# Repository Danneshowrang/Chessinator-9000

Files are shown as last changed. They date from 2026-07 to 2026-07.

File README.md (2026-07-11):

# Chessinator-9000
A smart open source folding chessboard. Future expansions planned with electromagnetic gantry.


# About
This board utilizes a network of hall sensors to track and log moves. Made up of 2 adjacent PCBs and designed to be foldable for improved portability. Future plans include a supplementary electromagnetic gantry and API connection to Lichess and Chess.com. Currently configured to project move and take a crowdvote for Open Sauce.

# Pictures
Screenshot 2026-07-11 at 2 22 00 AM
Chessinator_9000_Assembly_2_v1_2026-Jul-11_06-53-40AM-000_CustomizedView4809420216_jpg




# CAD
Link to Onshape: https://cad.onshape.com/documents/2e4e2dec579cd54b02eea52a/w/9b3b1f51bd0c7211bdccebd8/e/a09db839a12e81c960572c26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

# Bill Of Materials
Screenshot 2026-07-11 at 6 36 42 AM

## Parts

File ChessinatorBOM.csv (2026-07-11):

Name | Price | Link | Quantity
XT30 Plug* | $0.38 | https://jlcpcb.com/partdetail/Changzhou_AmassElec-XT30PW_M30_GY/C431092 | 1
Hall Sensor* | $0.11 | https://jlcpcb.com/partdetail/GoChip_Elec_Tech_Shanghai-GH49FEUAC/C92332 | 64
3.4A Inductor* | $0.06 | https://jlcpcb.com/partdetail/146573-SMNR4020_22UH/C135262 | 3
10A Fuse* | $0.21 | https://jlcpcb.com/partdetail/BHFUSE-BSMD1206L500/C914097 | 2
23V Diode* | $4.75 | https://jlcpcb.com/partdetail/10752-SMBJ18A/C10212 | 2
Polarized Caps* | $0.04 | https://jlcpcb.com/partdetail/DMBJ-RVT1E470M0605_47UF25V/C970677 | 2
AO3401A MOSFET | $0.10 | https://jlcpcb.com/partdetail/Alpha_OmegaSemicon-AO3401A/C15127 | 2
12-pin FFC* | $0.10 | https://jlcpcb.com/partdetail/JUSHUO-AFC07_S12FCA00/C262559 | 2
Ceramic Caps | $0.03 | https://jlcpcb.com/partdetail/YAGEO-CC0603KRX7R9BB104/C14663 | 4
ESP-32-S3-N16* | $5.42 | https://jlcpcb.com/partdetail/3198297-ESP32_S3_WROOM_1N16/C2913199 | 1
SOIC-24 MUX* | $0.67 | https://jlcpcb.com/partdetail/TexasInstruments-CD74HC4067M96/C496123 | 4
3.3V Buck* | $0.61 | https://jlcpcb.com/partdetail/DiodesIncorporated-AP63203WU7/C780769 | 1
5V Buck* | $0.56 | https://jlcpcb.com/partdetail/DiodesIncorporated-AP63201WU7/C2071044 | 1
USB-C* | $0.10 | https://jlcpcb.com/partdetail/HCTL-HC_TYPE_C_16P01A/C2894897 | 1
Gross: | $27.49 | "+ shipping"
Pick & Place: | 36 | * - +$3 one-time extended fee for pick and place machine
Total: | $63.49

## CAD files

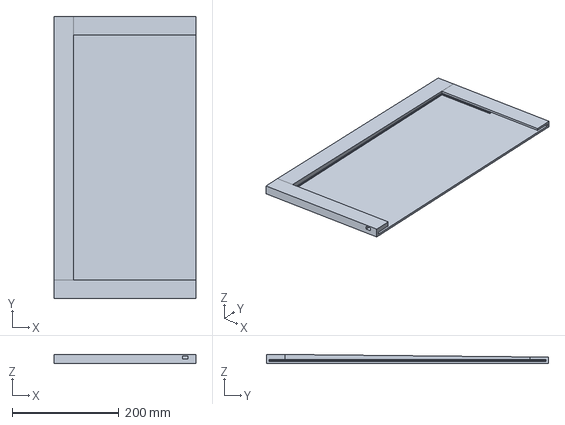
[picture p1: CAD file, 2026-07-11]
Chessinator CAD Files/Chessinator 9000 Left Case Piece.step
264.9 x 527.3 x 17.0 mm

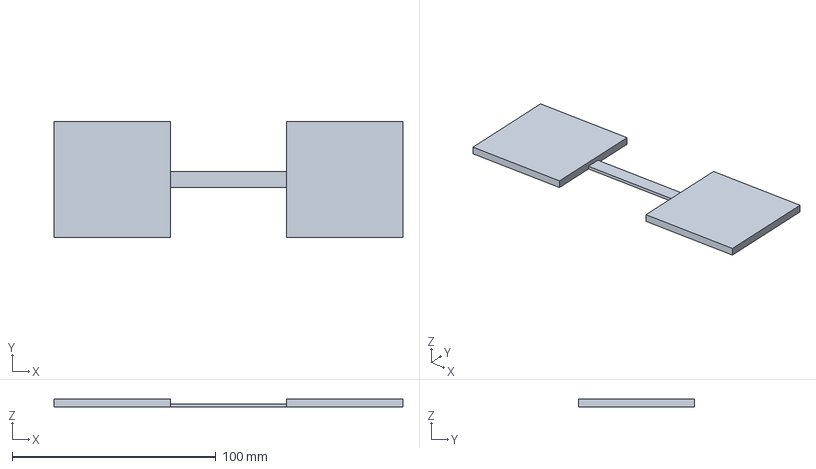
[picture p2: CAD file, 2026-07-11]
Chessinator CAD Files/Chessinator 9000 Dark Square Piece.step
171.4 x 57.1 x 4.00 mm

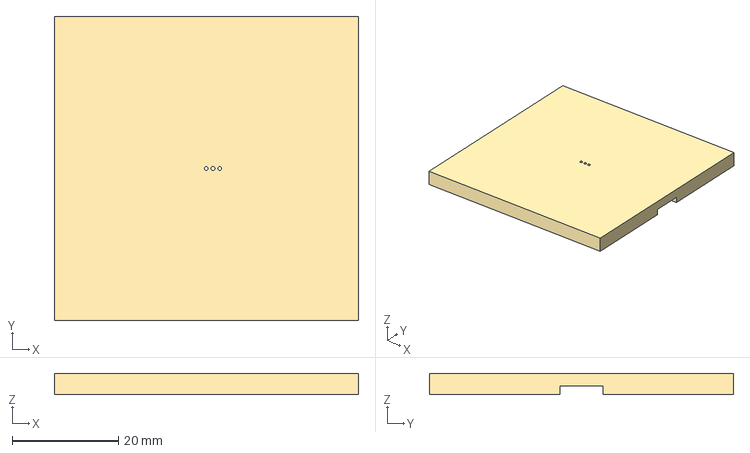
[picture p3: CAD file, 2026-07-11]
Chessinator CAD Files/Chessinator 9000 Light Square Piece.step
57.1 x 57.1 x 4.00 mm

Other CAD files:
Chessinator CAD Files/Chessinator 9000 Right Case Piece.step

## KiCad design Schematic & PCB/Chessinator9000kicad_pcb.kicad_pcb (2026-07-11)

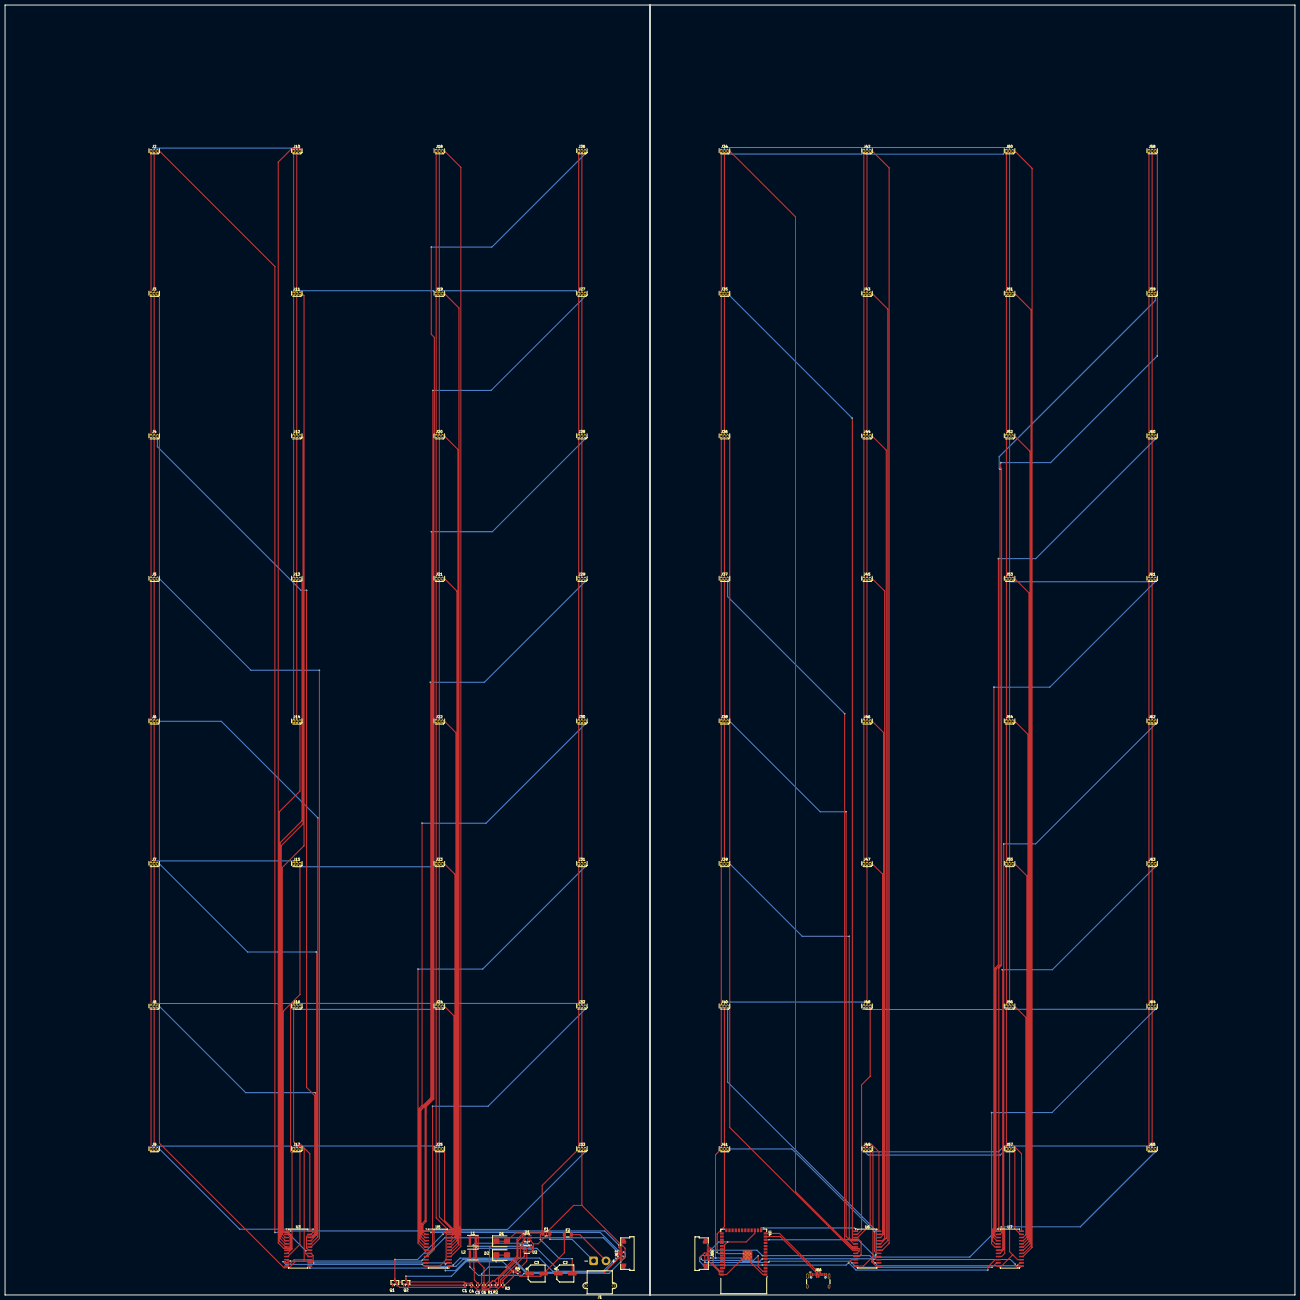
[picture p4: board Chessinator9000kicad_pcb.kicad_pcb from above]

Board: 2 copper layers, 517.1 x 517.1 mm, 93 parts (0 on the bottom side), 91 nets.

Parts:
C1, C4, C5, C6: C; C_0603_1608Metric
C2, C3: C_Polarized; CP_Elec_6.3x5.4
D1, D2: D_TVS; D_SMB
F1, F2: Fuse; Fuse_1206_3216Metric
J1: Conn_01x02; AMASS_XT30PW-M_1x02_P2.50mm_Horizontal
J2, J3, J4, J5, J6, J7, J8, J9, J10, J11, J12, J13, J14, J15, J16, J17, J18, J19, J20, J21, J22, J23, J24, J25, J26, J27, J28, J29, J30, J31, J32, J33, J34, J35, J36, J37, J38, J39, J40, J41, J42, J43, J44, J45, J46, J47, J48, J49, J50, J51, J52, J53, J54, J55, J56, J57, J58, J59, J60, J61, J62, J63, J64, J65: Conn_01x03; TO-92S
J66: USB_C_Receptacle_USB2.0_16P; USB_C_Receptacle_HCTL_HC-TYPE-C-16P-01A
J67, J68: Conn_02x06_Odd_Even; Amphenol_F32Q-1A7x1-11012_1x12-1MP_P0.5mm_Horizontal
L1, L2: L; L_Coilcraft_XxL4020
Q1, Q2: PMOS; SOT-23
R1, R2, R3, R4: R; R_0603_1608Metric
U1: AP63203WU; TSOT-23-6
U2: AP63201WU; TSOT-23-6
U3, U5, U6, U7: CD74HC4067M; SOIC-24W_7.5x15.4mm_P1.27mm
U4: ESP32-S3-WROOM-1

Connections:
+3V3: C2.2, D1.1 (A1), D1.2 (A2), F1.1, J2.1 (VCC), J3.1 (VCC), J4.1 (VCC), J5.1 (VCC), J6.1 (VCC), J7.1 (VCC), J8.1 (VCC), J9.1 (VCC), J10.1 (VCC), J11.1 (VCC), J12.1 (VCC), J13.1 (VCC), J14.1 (VCC), J15.1 (VCC), J16.1 (VCC), J17.1 (VCC), J18.1 (VCC), J19.1 (VCC), J20.1 (VCC), J21.1 (VCC), J22.1 (VCC), J23.1 (VCC), J24.1 (VCC), J25.1 (VCC), J26.1 (VCC), J27.1 (VCC), J28.1 (VCC), J29.1 (VCC), J30.1 (VCC), J31.1 (VCC), J32.1 (VCC), J33.1 (VCC), J34.1 (VCC), J35.1 (VCC), J36.1 (VCC), J37.1 (VCC), J38.1 (VCC), J39.1 (VCC), J40.1 (VCC), J41.1 (VCC), J42.1 (VCC), J43.1 (VCC), J44.1 (VCC), J45.1 (VCC), J46.1 (VCC), J47.1 (VCC), J48.1 (VCC), J49.1 (VCC), J50.1 (VCC), J51.1 (VCC), J52.1 (VCC), J53.1 (VCC), J54.1 (VCC), J55.1 (VCC), J56.1 (VCC), J57.1 (VCC), J58.1 (VCC), J59.1 (VCC), J60.1 (VCC), J61.1 (VCC), J62.1 (VCC), J63.1 (VCC), J64.1 (VCC), J65.1 (VCC), J67.3, J67.4, J68.9, J68.10, Q1.3 (S), R1.1, R2.1, U3.24 (VCC), U4.2 (3V3), U5.24 (VCC), U6.24 (VCC), U7.24 (VCC)
+5V: C3.2, D2.1 (A1), D2.2 (A2), F2.1, Q2.3 (S), R3.1, R4.1
/Untitled Sheet/MUX3_COM: J67.9, J68.4, U4.17 (IO9), U4.38 (IO2), U5.1 (COM)
/Untitled Sheet/MUX4_COM: J67.10, J68.3
/Untitled Sheet/MUX_COM_EXTRA: J67.11, J68.2, U3.1 (COM), U4.39 (IO1)
/Untitled Sheet/MUX_S0: J67.5, J68.8, U3.10 (S0), U4.4 (IO4), U5.10 (S0), U6.10 (S0), U7.10 (S0)
/Untitled Sheet/MUX_S1: J67.6, J68.7, U3.11 (S1), U4.5 (IO5), U5.11 (S1), U6.11 (S1), U7.11 (S1)
/Untitled Sheet/MUX_S2: J67.7, J68.6, U3.14 (S2), U4.6 (IO6), U5.14 (S2), U6.14 (S2), U7.14 (S2)
/Untitled Sheet/MUX_S3: J67.8, J68.5, U3.13 (S3), U4.7 (IO7), U5.13 (S3), U6.13 (S3), U7.13 (S3)
GND: J2.2 (GND), J3.2 (GND), J4.2 (GND), J5.2 (GND), J6.2 (GND), J7.2 (GND), J8.2 (GND), J9.2 (GND), J10.2 (GND), J11.2 (GND), J12.2 (GND), J13.2 (GND), J14.2 (GND), J15.2 (GND), J16.2 (GND), J17.2 (GND), J18.2 (GND), J19.2 (GND), J20.2 (GND), J21.2 (GND), J22.2 (GND), J23.2 (GND), J24.2 (GND), J25.2 (GND), J26.2 (GND), J27.2 (GND), J28.2 (GND), J29.2 (GND), J30.2 (GND), J31.2 (GND), J32.2 (GND), J33.2 (GND), J34.2 (GND), J35.2 (GND), J36.2 (GND), J37.2 (GND), J38.2 (GND), J39.2 (GND), J40.2 (GND), J41.2 (GND), J42.2 (GND), J43.2 (GND), J44.2 (GND), J45.2 (GND), J46.2 (GND), J47.2 (GND), J48.2 (GND), J49.2 (GND), J50.2 (GND), J51.2 (GND), J52.2 (GND), J53.2 (GND), J54.2 (GND), J55.2 (GND), J56.2 (GND), J57.2 (GND), J58.2 (GND), J59.2 (GND), J60.2 (GND), J61.2 (GND), J62.2 (GND), J63.2 (GND), J64.2 (GND), J65.2 (GND), J67.1, J67.2, J68.11, J68.12, U1.4 (GND), U2.4 (GND), U3.12 (GND), U3.15 (~E), U4.1 (GND), U4.40 (GND), U4.41 (GND), U5.12 (GND), U5.15 (~E), U6.12 (GND), U6.15 (~E), U7.12 (GND), U7.15 (~E)
unnamed: C2.1, L1.1
unnamed: C3.1, L2.1
unnamed: F1.2, J1.1
unnamed: F2.2, J1.2
unnamed: J2.3 (PIT), U3.16 (I15)
unnamed: J3.3 (PIT), U3.17 (I14)
unnamed: J4.3 (PIT), U3.18 (I13)
unnamed: J5.3 (PIT), U3.19 (I12)
unnamed: J6.3 (PIT), U3.20 (I11)
unnamed: J7.3 (PIT), U3.21 (I10)
unnamed: J8.3 (PIT), U3.22 (I9)
unnamed: J9.3 (PIT), U3.23 (I8)
unnamed: J10.3 (PIT), U3.2 (I7)
unnamed: J11.3 (PIT), U3.3 (I6)
unnamed: J12.3 (PIT), U3.4 (I5)
unnamed: J13.3 (PIT), U3.5 (I4)
unnamed: J14.3 (PIT), U3.6 (I3)
unnamed: J15.3 (PIT), U3.7 (I2)
unnamed: J16.3 (PIT), U3.8 (I1)
unnamed: J17.3 (PIT), U3.9 (I0)
unnamed: J18.3 (PIT), U5.16 (I15)
unnamed: J19.3 (PIT), U5.17 (I14)
unnamed: J20.3 (PIT), U5.18 (I13)
unnamed: J21.3 (PIT), U5.19 (I12)
unnamed: J22.3 (PIT), U5.20 (I11)
unnamed: J23.3 (PIT), U5.21 (I10)
unnamed: J24.3 (PIT), U5.22 (I9)
unnamed: J25.3 (PIT), U5.23 (I8)
unnamed: J26.3 (PIT), U5.2 (I7)
unnamed: J27.3 (PIT), U5.3 (I6)
unnamed: J28.3 (PIT), U5.4 (I5)
unnamed: J29.3 (PIT), U5.5 (I4)
unnamed: J30.3 (PIT), U5.6 (I3)
unnamed: J31.3 (PIT), U5.7 (I2)
unnamed: J32.3 (PIT), U5.8 (I1)
unnamed: J33.3 (PIT), U5.9 (I0)
unnamed: J34.3 (PIT), U6.8 (I1)
unnamed: J35.3 (PIT), U6.9 (I0)
unnamed: J36.3 (PIT), U6.7 (I2)
unnamed: J37.3 (PIT), U6.6 (I3)
unnamed: J38.3 (PIT), U6.5 (I4)
unnamed: J39.3 (PIT), U6.4 (I5)
unnamed: J40.3 (PIT), U6.16 (I15)
unnamed: J41.3 (PIT), U6.17 (I14)
unnamed: J42.3 (PIT), U6.18 (I13)
unnamed: J43.3 (PIT), U6.19 (I12)
unnamed: J44.3 (PIT), U6.20 (I11)
unnamed: J45.3 (PIT), U6.21 (I10)
unnamed: J46.3 (PIT), U6.22 (I9)
unnamed: J47.3 (PIT), U6.23 (I8)
unnamed: J48.3 (PIT), U6.2 (I7)
unnamed: J49.3 (PIT), U6.3 (I6)
unnamed: J50.3 (PIT), U7.16 (I15)
unnamed: J51.3 (PIT), U7.17 (I14)
unnamed: J52.3 (PIT), U7.18 (I13)
unnamed: J53.3 (PIT), U7.19 (I12)
unnamed: J54.3 (PIT), U7.20 (I11)
unnamed: J55.3 (PIT), U7.21 (I10)
unnamed: J56.3 (PIT), U7.22 (I9)
unnamed: J57.3 (PIT), U7.23 (I8)
unnamed: J58.3 (PIT), U7.2 (I7)
unnamed: J59.3 (PIT), U7.3 (I6)
unnamed: J60.3 (PIT), U7.4 (I5)
unnamed: J61.3 (PIT), U7.5 (I4)
unnamed: J62.3 (PIT), U7.9 (I0)
unnamed: J63.3 (PIT), U7.8 (I1)
unnamed: J64.3 (PIT), U7.6 (I3)
unnamed: J65.3 (PIT), U7.7 (I2)
unnamed: C1.2, C4.2, Q1.1 (D), Q2.1 (D), U1.2 (EN), U1.3 (IN), U2.2 (EN), U2.3 (IN)
unnamed: C1.1, Q1.2 (G)
unnamed: C4.1, Q2.2 (G)
unnamed: C5.1, U1.6 (BST)
unnamed: R1.2, R2.2, U1.1 (FB)
unnamed: C5.2, L1.2, U1.5 (SW)
unnamed: C6.1, U2.6 (BST)
unnamed: R3.2, R4.2, U2.1 (FB)
unnamed: C6.2, L2.2, U2.5 (SW)
unnamed: U4.15 (IO3), U6.1 (COM)
unnamed: U4.12 (IO8), U7.1 (COM)
unnamed: J66.A6 (D+), J66.B6 (D+), U4.14 (USB_D+)
unnamed: J66.A7 (D-), J66.B7 (D-), U4.13 (USB_D-)

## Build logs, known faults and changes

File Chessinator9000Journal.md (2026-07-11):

<!--
  This journal is auto generated by Stasis.
-->

# 7/11/2026 10 AM - Day 8

_Time spent: 9h_

Way easier day after all that. Started the case in OnShape, mostly just working off the exact board dimensions I already had locked in from the PCB. Hinge, the electronics compartment, cutout for the ribbon cable. Went smoothly, no real fights here, just straightforward modeling once I had the right measurements to work from.

Screenshot 2026-07-11 at 5.08.53 AM

Screenshot 2026-07-11 at 5.08.44 AM

Also wrote a first pass at the firmware. Got the ESP32 hosting a simple webpage where people can vote on moves, tallying votes, and sending the winner off to a laptop running a chess engine to get the reply. Added the Hall Sensor flashing logic to show the move on the board, and basic code to read the hall sensors and pause them during the actual move so a lifted piece mid swap doesn't trigger something weird. It's a rough first version, not fully tested yet, but the structure's there.

Screenshot 2026-07-11 at 2.22.00 AM

Chessinator_9000_Assembly_2_v1_2026-Jul-11_06-53-40AM-000_CustomizedView4809420216_jpg






# 7/11/2026 10 AM - Day 7

_Time spent: 10h_

Ran the final error check today and started going through everything it flagged. Turns out a lot of the warnings were actually fine, not real problems. Like the USB-C port has some pins that are supposed to be connected to each other, so the checker thinks it's a mistake even though it's normal. Same with a few other things, once I understood why they were flagged, they were easy to dismiss.

Screenshot 2026-07-11 at 4.59.57 AM

The connections crossing between my two board halves also show up as errors since there's no actual wire there in the design file, the physical ribbon cable handles that part. Had to go through and manually mark each of those as fine once I confirmed they were the expected ones.

Screenshot 2026-07-11 at 5.02.51 AM

Finally got everything down to zero real errors. Board's done, parts list is done.




# 7/11/2026 9 AM - Day 6

_Time spent: 11h_

This was the worst day of all time, ever, in history. Somewhere earlier in the project, two things that were supposed to be separate, like ground and power, accidentally got connected without me realizing. The software just quietly merged them into one, and suddenly every single ground connection on the whole board was showing up as a 3v3. I had no idea why for hours. Tried deleting things, reconnecting things, none of it actually fixed the real problem because I was fixing the symptoms instead of the actual cause.

Screenshot 2026-07-11 at 4.53.59 AM

Screenshot 2026-07-11 at 4.56.16 AM

Eventually found it, way back from something I'd basically ignored earlier because I thought it wasn't a big deal. Lesson learned, don't ignore warnings just because fixing them seems annoying in the moment. Genuinely spent an entire day trying to desperately fix this phantom error.

Screenshot 2026-07-11 at 4.57.01 AM





# 7/11/2026 9 AM - Day 5

_Time spent: 13_

Spent basically the whole day trying to get all 64 sensors placed in a perfectly even grid, using the official chess board spacing. Kept running into small alignment issues, like things drifting slightly off as I moved across columns, and one side of the board ended up not quite matching the other side by a couple millimeters. Had to keep recalculating and nudging things to get it centered right. 

Screenshot 2026-07-11 at 4.49.51 AM

Screenshot 2026-07-11 at 4.50.36 AM

Honestly this took way longer than it should have. It still have no clue what wasnt right, because it should have just been math. I think the footprint center might be a little off center which has messed with my calculations. At the end, I manually typed up coordinates for EACH component MULTIPLE TIMES!!!!!
Yes... MULTIPLE TIMES.




# 7/11/2026 9 AM - Day 4

_Time spent: 8h_

Today, things got messy (was that tuff?) I needed to split the circuit board into two halves so it can fold up small enough to fit in a carry on. Sounded easy in my head. Was not easy. Notttttt easy at ALL.

Screenshot 2026-07-11 at 4.42.45 AM

I split it the wrong way first, sideways instead of the way it actually needed to fold, and had to redo the whole layout because it didn't line up with how I'd grouped the hall sensors, which I had done by drawing a specific distance wire and placing another at the end which took a PAINSTAKINGLY long time.

Screenshot 2026-07-11 at 4.43.50 AM

Then I had to figure out a ribbon cable connector to link the two halves together, since they need to share power and talk to each other. I went back and forth on how many pins I actually needed a few times, ended up doubling up some connections just to be safe on power. Also had one connector that wasn't lining up right for the fold, took me forever to even figure out what was wrong, let alone fix it.

Screenshot 2026-07-11 at 4.45.39 AM





# 7/11/2026 9 AM - Day 3

_Time spent: 6h_

I ran the checker tool today, which revealed many problems that I corrected painstakingly I had a resistor wired to the wrong spot, which meant the voltage regulator had no way of knowing what voltage it was actually putting out. That one ook me a while to fix because I kept putting the wire back in the wrong place a few times and claude wasnt helping me troubleshoot it very well.

Screenshot 2026-07-11 at 4.36.27 AM

Screenshot 2026-07-11 at 4.37.20 AM

Screenshot 2026-07-11 at 4.37.50 AM

I also added a USB-C port as a backup way to update the firmware, in case wifi isn't reliable wherever I end up using this.

Screenshot 2026-07-11 at 4.38.31 AM






# 7/11/2026 9 AM - Day 2

_Time spent: 4h_

I wired up all 64 hall sensors today. Used four multiplexer chips so I don't need a separate wire for every single sensor, that would've been way too many pins. Shared the control lines across all four chips to save GPIOs on the microcontroller.

Screenshot 2026-07-11 at 4.29.39 AM

I almost accidentally used four separate microcontrollers instead of one, caught that before it became a real problem. Would've been a pain to undo later.

Screenshot 2026-07-11 at 4.30.27 AM

Keeping the schematic from turning into a total mess with 64 little sensor connections was honestly the hardest part today.

Screenshot 2026-07-11 at 4.31.23 AM





# 7/11/2026 9 AM - Day 1

_Time spent: 5h_

Today I got the schematic going. It's powered by an XT30 connector, 12V comes in through that. I put a MOSFET in there backwards on purpose so if I plug it in wrong it doesn't fry anything. Also added a diode and a fuse since I've got 64 hall sensors.

Screenshot 2026-07-11 at 4.22.05 AM

I stepped the voltage down twice, 12V to 5V for the lights, then 5V to 3.3V for the ESP32 and the sensor chips, and then spent way too long just looking for parts in KiCad that don't actually exist in the default library. Ended up using generic placeholders and renaming them, which I should've just done from the start instead of searching for so long.

Screenshot 2026-07-11 at 4.23.13 AM




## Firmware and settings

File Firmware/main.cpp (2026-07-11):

/*
 * Foldable Chess Sensing Board — Crowd Vote Firmware
 * ESP32-S3-WROOM-1
 *
 * Flow:
 *  1. Connect to venue WiFi
 *  2. Host a web page (reachable via QR code) listing candidate moves
 *  3. Collect votes for a timed window
 *  4. POST the winning move to a companion relay server (laptop running
 *     Stockfish / Lichess API bridge) for validation + next-move suggestion
 *  5. Flash WS2812B LEDs on the winning move's from/to squares
 *  6. Blank hall sensors during the move window, then rescan to verify
 *     the human actually made the move
 *
 * Libraries needed (PlatformIO lib_deps):
 *   ESP Async WebServer
 *   AsyncTCP
 *   ArduinoJson
 *   Adafruit NeoPixel
 *
 * Hardware:
 *   4x CD74HC4067 mux, 16 hall sensors each (64 total)
 *   64x WS2812B LEDs, one per square, single data pin
 *   4 shared select lines (S0-S3), 4 separate COM->ADC lines
 */

#include <WiFi.h>
#include <ESPAsyncWebServer.h>
#include <ArduinoJson.h>
#include <Adafruit_NeoPixel.h>

// ---------- Pin map (match schematic labels) ----------
constexpr uint8_t PIN_MUX_S0   = 4;
constexpr uint8_t PIN_MUX_S1   = 5;
constexpr uint8_t PIN_MUX_S2   = 6;
constexpr uint8_t PIN_MUX_S3   = 7;

constexpr uint8_t PIN_MUX1_COM = 1;   // IO1 - ADC
constexpr uint8_t PIN_MUX2_COM = 2;   // IO2 - ADC
constexpr uint8_t PIN_MUX3_COM = 38;  // IO38 - ADC (via J67/FFC)
constexpr uint8_t PIN_MUX4_COM = 39;  // IO39 - ADC (via J67/FFC)

constexpr uint8_t PIN_LED_DATA = 12;

constexpr uint8_t NUM_LEDS = 64;
constexpr uint8_t NUM_MUX  = 4;
constexpr uint8_t NUM_CH   = 16;

// ---------- WiFi / server config ----------
const char* WIFI_SSID = "YOUR_VENUE_SSID";
const char* WIFI_PASS = "YOUR_VENUE_PASS";

// Laptop relay server running Stockfish / Lichess bridge
const char* RELAY_HOST = "192.168.1.50";
const uint16_t RELAY_PORT = 8000;

AsyncWebServer server(80);
Adafruit_NeoPixel strip(NUM_LEDS, PIN_LED_DATA, NEO_GRB + NEO_KHZ800);

// ---------- Vote state ----------
struct VoteTally {
  String move;
  uint32_t count;
};

std::vector<VoteTally> currentCandidates;
std::vector<String> receivedVotes;
bool votingOpen = false;
uint32_t voteWindowMs = 20000;   // 20s voting window
uint32_t voteStartTime = 0;

// ---------- Hall sensor raw readings ----------
uint16_t hallRaw[NUM_MUX][NUM_CH];

const uint8_t muxCOMPins[NUM_MUX] = {
  PIN_MUX1_COM, PIN_MUX2_COM, PIN_MUX3_COM, PIN_MUX4_COM
};

// ---------- Forward declarations ----------
void setMuxChannel(uint8_t ch);
void scanAllHallSensors();
String buildVotePageHTML();
void startVotingRound(std::vector<String> candidateMoves);
void tallyAndResolveVote();
void sendMoveToRelay(const String& move);
void flashMoveOnBoard(const String& fromSquare, const String& toSquare);
uint8_t squareToLedIndex(const String& square);

void setup() {
  Serial.begin(115200);

  pinMode(PIN_MUX_S0, OUTPUT);
  pinMode(PIN_MUX_S1, OUTPUT);
  pinMode(PIN_MUX_S2, OUTPUT);
  pinMode(PIN_MUX_S3, OUTPUT);

  strip.begin();
  strip.show();

  WiFi.begin(WIFI_SSID, WIFI_PASS);
  Serial.print("Connecting to WiFi");
  while (WiFi.status() != WL_CONNECTED) {
    delay(400);
    Serial.print(".");
  }
  Serial.println();
  Serial.print("Connected. IP: ");
  Serial.println(WiFi.localIP());
  Serial.println("Point QR code / browsers at http://" + WiFi.localIP().toString());

  // ---- Web routes ----
  server.on("/", HTTP_GET, [](AsyncWebServerRequest* request) {
    request->send(200, "text/html", buildVotePageHTML());
  });

  server.on("/vote", HTTP_POST, [](AsyncWebServerRequest* request) {
    if (!votingOpen) {
      request->send(409, "text/plain", "Voting closed");
      return;
    }
    if (request->hasParam("move", true)) {
      String move = request->getParam("move", true)->value();
      receivedVotes.push_back(move);
      request->send(200, "text/plain", "Vote recorded: " + move);
    } else {
      request->send(400, "text/plain", "Missing move param");
    }
  });

  server.on("/status", HTTP_GET, [](AsyncWebServerRequest* request) {
    JsonDocument doc;
    doc["voting_open"] = votingOpen;
    doc["votes_so_far"] = receivedVotes.size();
    if (votingOpen) {
      uint32_t elapsed = millis() - voteStartTime;
      doc["ms_remaining"] = (elapsed < voteWindowMs) ? (voteWindowMs - elapsed) : 0;
    }
    String out;
    serializeJson(doc, out);
    request->send(200, "application/json", out);
  });

  server.begin();

  // Kick off the very first voting round with a placeholder candidate list.
  // In production, candidateMoves should come from the relay server's
  // Stockfish output (top N candidate moves for the current position).
  std::vector<String> demoMoves = {"e2e4", "d2d4", "g1f3", "c2c4"};
  startVotingRound(demoMoves);
}

void loop() {
  if (votingOpen && (millis() - voteStartTime >= voteWindowMs)) {
    tallyAndResolveVote();
  }
  delay(50);
}

// ---------------------------------------------------------------
// Mux control
// ---------------------------------------------------------------
void setMuxChannel(uint8_t ch) {
  digitalWrite(PIN_MUX_S0, ch & 0x01);
  digitalWrite(PIN_MUX_S1, (ch >> 1) & 0x01);
  digitalWrite(PIN_MUX_S2, (ch >> 2) & 0x01);
  digitalWrite(PIN_MUX_S3, (ch >> 3) & 0x01);
  delayMicroseconds(5); // settle time
}

void scanAllHallSensors() {
  for (uint8_t ch = 0; ch < NUM_CH; ch++) {
    setMuxChannel(ch);
    for (uint8_t m = 0; m < NUM_MUX; m++) {
      hallRaw[m][ch] = analogRead(muxCOMPins[m]);
    }
  }
}

// ---------------------------------------------------------------
// Voting
// ---------------------------------------------------------------
void startVotingRound(std::vector<String> candidateMoves) {
  currentCandidates.clear();
  for (auto& m : candidateMoves) {
    currentCandidates.push_back({m, 0});
  }
  receivedVotes.clear();
  votingOpen = true;
  voteStartTime = millis();
  Serial.println("Voting round started with " + String(candidateMoves.size()) + " candidates");
}

void tallyAndResolveVote() {
  votingOpen = false;

  for (auto& v : receivedVotes) {
    for (auto& c : currentCandidates) {
      if (c.move == v) c.count++;
    }
  }

  String winner = "";
  uint32_t best = 0;
  for (auto& c : currentCandidates) {
    if (c.count > best) {
      best = c.count;
      winner = c.move;
    }
  }

  if (winner == "" && !currentCandidates.empty()) {
    winner = currentCandidates[0].move; // fallback if no votes came in
  }

  Serial.println("Winning move: " + winner + " (" + String(best) + " votes)");

  sendMoveToRelay(winner);
}

// ---------------------------------------------------------------
// Relay communication (laptop running Stockfish bridge)
// ---------------------------------------------------------------
void sendMoveToRelay(const String& move) {
  WiFiClient client;
  if (!client.connect(RELAY_HOST, RELAY_PORT)) {
    Serial.println("Relay connection failed");
    return;
  }

  JsonDocument doc;
  doc["move"] = move;
  String body;
  serializeJson(doc, body);

  client.println("POST /move HTTP/1.1");
  client.println("Host: " + String(RELAY_HOST));
  client.println("Content-Type: application/json");
  client.println("Content-Length: " + String(body.length()));
  client.println();
  client.println(body);

  // Wait briefly for a response containing from/to squares + next candidates
  uint32_t start = millis();
  String response;
  while (client.connected() && millis() - start < 5000) {
    while (client.available()) {
      response += (char)client.read();
    }
  }
  client.stop();

  // crude parse: expects a trailing JSON body from the relay, e.g.
  // {"from":"e2","to":"e4","next_candidates":["e7e5","c7c5","e7e6"]}
  int jsonStart = response.indexOf('{');
  if (jsonStart >= 0) {
    JsonDocument respDoc;
    DeserializationError err = deserializeJson(respDoc, response.substring(jsonStart));
    if (!err) {
      String from = respDoc["from"] | "";
      String to   = respDoc["to"]   | "";
      if (from.length() && to.length()) {
        flashMoveOnBoard(from, to);
      }

      std::vector<String> nextMoves;
      if (respDoc["next_candidates"].is<JsonArray>()) {
        for (JsonVariant v : respDoc["next_candidates"].as<JsonArray>()) {
          nextMoves.push_back(v.as<String>());
        }
      }
      if (!nextMoves.empty()) {
        startVotingRound(nextMoves);
      }
      return;
    }
  }
  Serial.println("Failed to parse relay response");
}

// ---------------------------------------------------------------
// LED display + move verification
// ---------------------------------------------------------------
uint8_t squareToLedIndex(const String& square) {
  // "e4" -> file e (0-7), rank 4 (0-7) -> index = rank*8 + file
  if (square.length() < 2) return 255;
  char file = square[0];
  char rank = square[1];
  if (file < 'a' || file > 'h') return 255;
  if (rank < '1' || rank > '8') return 255;
  uint8_t f = file - 'a';
  uint8_t r = rank - '1';
  return r * 8 + f;
}

void flashMoveOnBoard(const String& fromSquare, const String& toSquare) {
  uint8_t fromIdx = squareToLedIndex(fromSquare);
  uint8_t toIdx   = squareToLedIndex(toSquare);

  if (fromIdx == 255 || toIdx == 255) {
    Serial.println("Invalid square in flashMoveOnBoard");
    return;
  }

  // Blank hall sensors are not physically possible (they're passive),
  // but we pause scanning/interpreting them during the flash+move window
  // so a lifted piece mid-move doesn't register as a false event.
  bool sensingPaused = true;

  for (int i = 0; i < 6; i++) {
    strip.setPixelColor(fromIdx, strip.Color(0, 255, 0));
    strip.setPixelColor(toIdx,   strip.Color(0, 100, 255));
    strip.show();
    delay(300);
    strip.clear();
    strip.show();
    delay(200);
  }

  // Give the human time to physically move the piece, then resume
  // sensing and verify placement.
  delay(4000);
  sensingPaused = false;

  scanAllHallSensors();
  // TODO: compare hallRaw against expected post-move magnet pattern
  // and re-flash toSquare in red if verification fails.
  Serial.println("Move window complete, sensors rescanned.");
}

// ---------------------------------------------------------------
// Web page
// ---------------------------------------------------------------
String buildVotePageHTML() {
  String html = R"HTML(
<!DOCTYPE html>
<html>
<head>
  <meta name="viewport" content="width=device-width, initial-scale=1">
  <title>Vote the Next Move</title>
  <style>
    body { font-family: sans-serif; text-align: center; background:#1a1a1a; color:#eee; }
    button { font-size: 1.5em; margin: 10px; padding: 14px 24px; border-radius: 10px; border:none; background:#3a7; color:#fff; }
    button:active { background:#284; }
    #status { margin-top: 20px; font-size: 1.1em; }
  </style>
</head>
<body>
  <h1>Vote for the Next Move</h1>
  <div id="candidates"></div>
  <div id="status">Loading...</div>

<script>
async function loadCandidates() {
  // In this simplified demo, candidates are hardcoded to match firmware.
  // Production version should fetch them from /status or a dedicated endpoint.
  const moves = ["e2e4", "d2d4", "g1f3", "c2c4"];
  const container = document.getElementById('candidates');
  container.innerHTML = '';
  moves.forEach(m => {
    const btn = document.createElement('button');
    btn.innerText = m;
    btn.onclick = () => vote(m);
    container.appendChild(btn);
  });
}

async function vote(move) {
  const res = await fetch('/vote', {
    method: 'POST',
    headers: {'Content-Type': 'application/x-www-form-urlencoded'},
    body: 'move=' + encodeURIComponent(move)
  });
  document.getElementById('status').innerText = await res.text();
}

async function pollStatus() {
  try {
    const res = await fetch('/status');
    const data = await res.json();
    if (data.voting_open) {
      document.getElementById('status').innerText =
        'Votes so far: ' + data.votes_so_far + ' | Time left: ' + Math.ceil(data.ms_remaining/1000) + 's';
    } else {
      document.getElementById('status').innerText = 'Voting closed, resolving winner...';
    }
  } catch(e) {}
}

loadCandidates();
setInterval(pollStatus, 1000);
</script>
</body>
</html>
)HTML";
  return html;
}

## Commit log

2026-07-11 Expand README with project details and features
    Added an 'About' section detailing the board's features and future plans.
2026-07-11 Enhance README with images and project updates
    Added images and updated project description with current features.
2026-07-11 Add CAD link to README
    Added a link to the Onshape CAD document.
2026-07-11 Add image to Bill Of Materials in README
    Added an image to the Bill Of Materials section.
